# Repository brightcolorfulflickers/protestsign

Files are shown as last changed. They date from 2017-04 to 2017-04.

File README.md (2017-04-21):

# protestsign

An electronic protest sign. #resist

## About

Since I forsee the need for lots of protesting in the future, I decided to make a reusable electronic protest sign. All messages are stored as a list in a text file on a micro SD card, so there's no need to reprogram the microcontroller to update the messages. If you buy an OTG micro SD card reader, you can even edit your messages on the go from your phone! Change the position of the dipswitch to display a new message.

## Instructions

Solder according to the schematic. The LED matrix should come with connectors. Make an extension cord long enough to hold the control board in your pocket or hand while you are holding the sign up.

Upload ProtestSign to the microcontroller. Copy messages.txt to a micro SD card and insert into the micro SD card slot.

Create your sign! I cut a 14"x14" square out of foam board with a box cutter. The grid lines made it easier to cut. Measure and mark so your LED matrix will be centered. Then attach velcro squares to the foam board and LED matrix back to mount it. This way you can remove the LED matrix in case it rains.

You may also wish to attach a handle or post to the sign. Many protests disallow wooden or metal sticks, so be sure to use some sturdy cardboard.

I have also included files for a case to be laser cut from acrylic. Be sure to slide the battery and LED connectors through the hole for them on the top plate. The microcontroller board should stick out from the slot on the side so you can access the micro SD card. Screw the proto board to the top of the case with a 4-40 screw. 

## Parts List

* [M0 Adalogger](https://www.adafruit.com/product/2796)
* [Perma Proto](https://www.adafruit.com/product/1608)
* [JST cable with switch](https://www.adafruit.com/product/3064)
* [2500 mAh LiPo battery](https://www.adafruit.com/product/328)
* Micro SD card
* [8*32 WS2812b LED array](https://www.aliexpress.com/item/8-8-16-16-8-32-Pixel-256-Pixels-WS2812B-Digital-Flexible-LED-Programmed-Panel-Screen/32584178296.html)
* [Dipswitch](https://www.digikey.com/product-detail/en/cts-electrocomponents/206-8/CT2068-ND/20760)
* [8x 10k ohm resistors ](https://www.digikey.com/product-detail/en/stackpole-electronics-inc/CF14JT10K0/CF14JT10K0CT-ND/1830374)
* [4700 uF capacitor](https://www.digikey.com/product-detail/en/nichicon/UVR0J472MHD/493-1010-ND/588751)
* [470 ohm resistor](https://www.digikey.com/product-detail/en/stackpole-electronics-inc/CF14JT470R/CF14JT470RCT-ND/1830342) (for LED data line)
* Foamboard - available at craft stores. Try to get the kind with the grid on it.
* [Velcro squares](http://www.joann.com/velcro-brand-sticky-back-squares/prd3165.html#q=Sticky+Velcro&start=1)
* [1/16" acrylic sheet](https://www.inventables.com/technologies/clear-acrylic-sheet)
* 4-40 machine screw and hex nuts

## Schematic

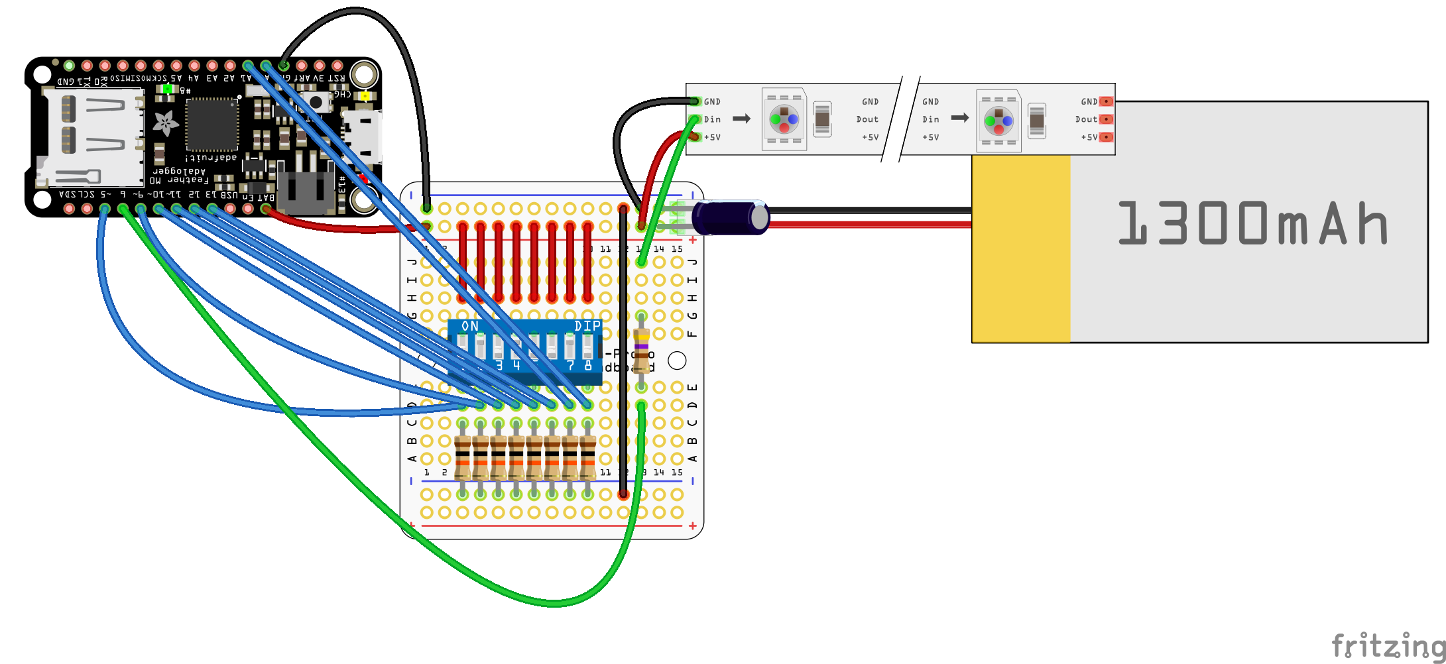
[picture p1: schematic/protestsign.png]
Schematic


## Photos

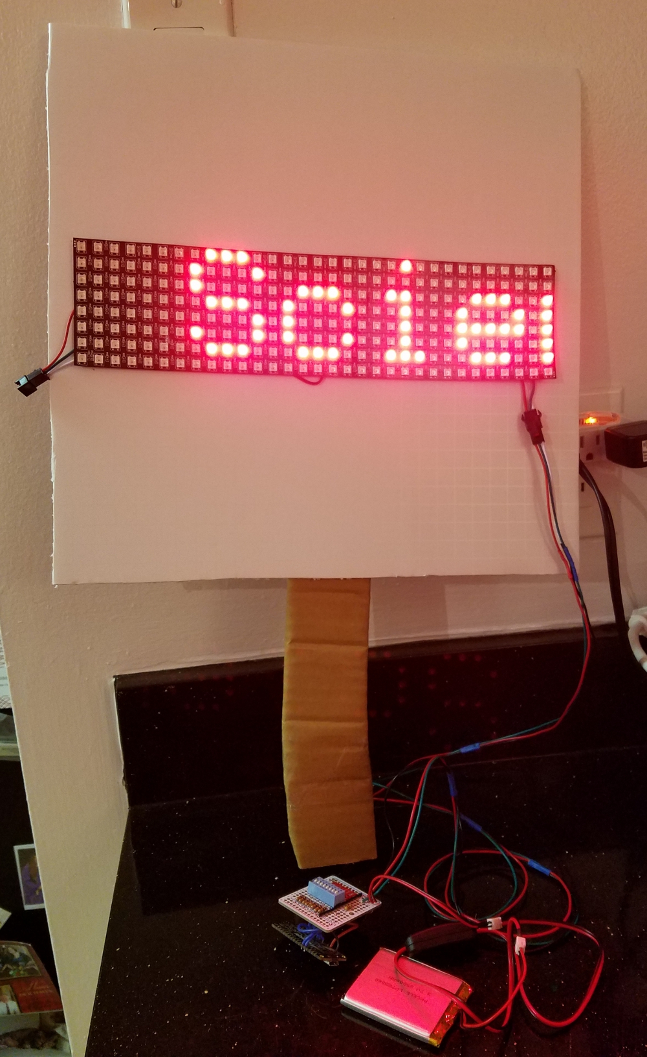
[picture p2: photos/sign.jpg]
Sign

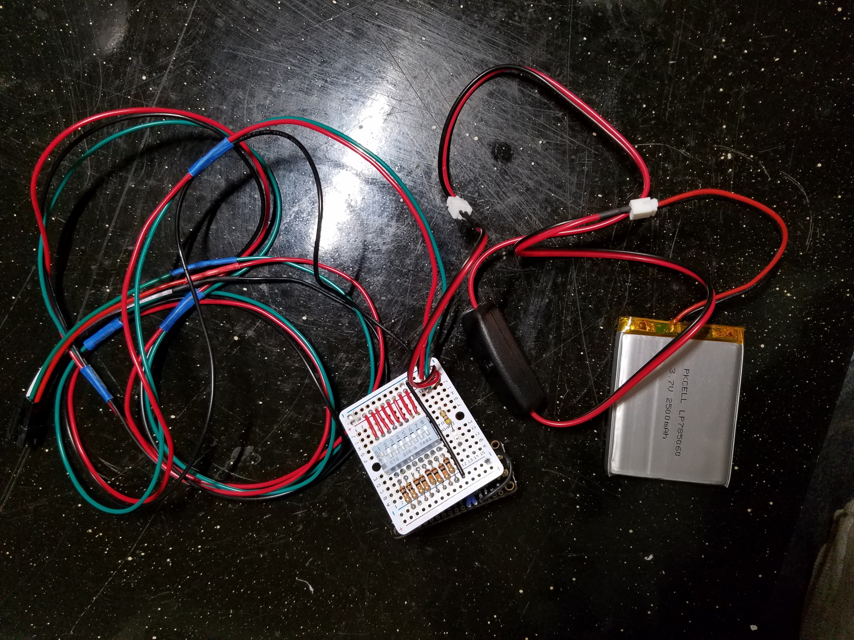
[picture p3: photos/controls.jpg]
Controls

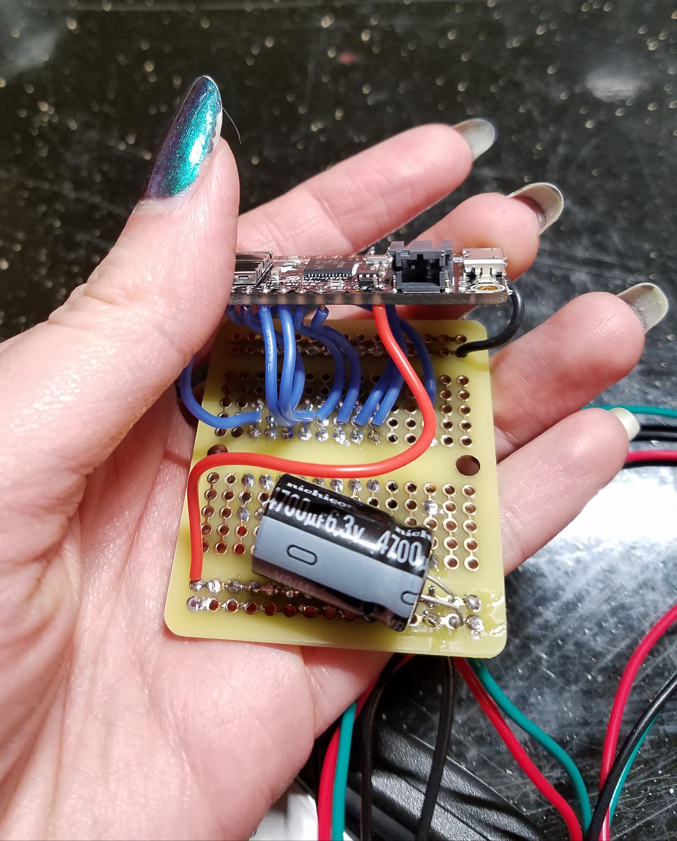
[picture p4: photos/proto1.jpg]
Protoboard

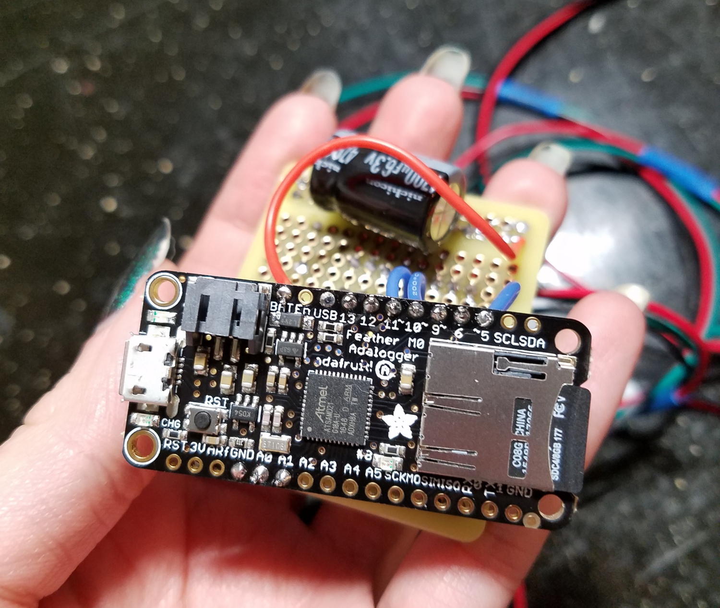
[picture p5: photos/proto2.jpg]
Microcontroller


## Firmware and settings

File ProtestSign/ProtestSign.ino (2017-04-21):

/*
 * LED Protest Sign
 * by brightcolorfulflickers
 * February 2017
 *
 * github.com/brightcolorfulflickers
 * brightcolorfulflickers.tumblr.com
 * instagram.com/brightcolorfulflickers
 */

#include <Adafruit_GFX.h>
#include <Adafruit_NeoMatrix.h>
#include <Adafruit_NeoPixel.h>
#include <SPI.h>
#include <SD.h>
#ifndef PSTR
 #define PSTR // Make Arduino Due happy
#endif

#define PIN 6

// MATRIX DECLARATION:
// Parameter 1 = width of NeoPixel matrix
// Parameter 2 = height of matrix
// Parameter 3 = pin number (most are valid)
// Parameter 4 = matrix layout flags, add together as needed:
//   NEO_MATRIX_TOP, NEO_MATRIX_BOTTOM, NEO_MATRIX_LEFT, NEO_MATRIX_RIGHT:
//     Position of the FIRST LED in the matrix; pick two, e.g.
//     NEO_MATRIX_TOP + NEO_MATRIX_LEFT for the top-left corner.
//   NEO_MATRIX_ROWS, NEO_MATRIX_COLUMNS: LEDs are arranged in horizontal
//     rows or in vertical columns, respectively; pick one or the other.
//   NEO_MATRIX_PROGRESSIVE, NEO_MATRIX_ZIGZAG: all rows/columns proceed
//     in the same order, or alternate lines reverse direction; pick one.
//   See example below for these values in action.
// Parameter 5 = pixel type flags, add together as needed:
//   NEO_KHZ800  800 KHz bitstream (most NeoPixel products w/WS2812 LEDs)
//   NEO_KHZ400  400 KHz (classic 'v1' (not v2) FLORA pixels, WS2811 drivers)
//   NEO_GRB     Pixels are wired for GRB bitstream (most NeoPixel products)
//   NEO_RGB     Pixels are wired for RGB bitstream (v1 FLORA pixels, not v2)


// Example for NeoPixel Shield.  In this application we'd like to use it
// as a 5x8 tall matrix, with the USB port positioned at the top of the
// Arduino.  When held that way, the first pixel is at the top right, and
// lines are arranged in columns, progressive order.  The shield uses
// 800 KHz (v2) pixels that expect GRB color data.
Adafruit_NeoMatrix matrix = Adafruit_NeoMatrix(32, 8, PIN,
  NEO_MATRIX_BOTTOM     + NEO_MATRIX_RIGHT +
  NEO_MATRIX_COLUMNS + NEO_MATRIX_ZIGZAG,
  NEO_GRB            + NEO_KHZ800);
const uint16_t colors[] = {
  matrix.Color(255, 0, 0), matrix.Color(0, 255, 0), matrix.Color(0, 0, 255) };
String textToPrint = "Hello world";  

const int buttonArray[] = {5,9,10,11,12,13,A1,A0};
const int lengthDipswitch = 8;
const int chipSelect = 4;


void setup() {
  matrix.begin();
  matrix.setTextWrap(false);
  matrix.setBrightness(255);
  matrix.setTextColor(colors[0]);
  for (int i=0; i < lengthDipswitch; i++) {
    pinMode(buttonArray[i], INPUT);
  }
  Serial.begin(9600);  
  Serial.print("Initializing SD card...");

  // see if the card is present and can be initialized:
  if (!SD.begin(chipSelect)) {
    Serial.println("Card failed, or not present");
    // don't do anything more:
    return;
  }
  Serial.println("card initialized.");  
}

int x    = matrix.width();
int pass = 0;
unsigned long prevFrameTime = 0L;             // For animation timing
#define FPS 15 
int checkMessage = 0;

void loop() {
  unsigned long t = millis();
  if((t - prevFrameTime) >= (1000L / FPS)) { // Handle scrolling
      matrix.fillScreen(0);
      matrix.setCursor(x, 0);
      matrix.print(textToPrint);
      int msgLen = (int)textToPrint.length()*6;
      if(--x < -msgLen) {
         x = matrix.width(); // We must repeat!
         checkMessage = 1;
         if(++pass >= 3) pass = 0;
            matrix.setTextColor(colors[pass]);
      }
    matrix.show();
    prevFrameTime = t;
  }
  
  if (checkMessage == 1) {
    int msgCount = 0;
    int msgIndex = readDipswitch();
    File dataFile = SD.open("messages.txt");
    // if the file is available, write to it:
    if (dataFile) {
      while (dataFile.available()) {
        String line = dataFile.readStringUntil('\n');
        if (msgCount == msgIndex) {
          textToPrint = line;  
          Serial.println(line);
        }
        msgCount++;
      }
      dataFile.close();
    }
    // if the file isn't open, pop up an error:
    else {
      Serial.println("error opening txt file");
    }
    checkMessage = 0;
  }
}

int readDipswitch() {
  int dipswitchRead[lengthDipswitch];
  int dipswitchSum = 0;
  for (int i=0; i < lengthDipswitch; i++) {
    dipswitchRead[i] = digitalRead(buttonArray[i]);
    dipswitchSum += dipswitchRead[i]*ipow(2,i);
  }

  return dipswitchSum;
}

int ipow(int base, int exponent) {
  int result = 1;
  while (exponent != 0)
  {
      if ((exponent & 1) == 1)
          result *= base;
      exponent >>= 1;
      base *= base;
  }

  return result;
}

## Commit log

2017-04-21 New schematic and code
    Updated to Adalogger M0. Updated code. Added photos.
    [protest sign.fzz]
2017-04-21 plans for laser cut case
2017-04-21 readme update - case
